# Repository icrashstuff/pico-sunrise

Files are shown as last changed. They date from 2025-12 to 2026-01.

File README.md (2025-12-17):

# pico-sunrise
A sunrise clock for RP2040 based microcontrollers

## Parts
- RP2040 based microcontroller (Raspberry Pi Pico) - Such as https://www.adafruit.com/product/4883
- PA1616S GPS Module - MTK3339 Chipset - Such as https://www.adafruit.com/product/746
- SK6812RGBW individually addressable LED strip - Such as https://www.adafruit.com/product/4913

## Configuration
[config.h](config.h)

## License (pico-sunrise)
Copyright (c) 2025 Ian Hangartner <icrashstuff at outlook dot com>

Permission is hereby granted, free of charge, to any person obtaining a
copy of this software and associated documentation files (the "Software"),
to deal in the Software without restriction, including without limitation
the rights to use, copy, modify, merge, publish, distribute, sublicense,
and/or sell copies of the Software, and to permit persons to whom the
Software is furnished to do so, subject to the following conditions:

The above copyright notice and this permission notice shall be included in
all copies or substantial portions of the Software.

THE SOFTWARE IS PROVIDED "AS IS", WITHOUT WARRANTY OF ANY KIND, EXPRESS OR
IMPLIED, INCLUDING BUT NOT LIMITED TO THE WARRANTIES OF MERCHANTABILITY,
FITNESS FOR A PARTICULAR PURPOSE AND NONINFRINGEMENT. IN NO EVENT SHALL THE
AUTHORS OR COPYRIGHT HOLDERS BE LIABLE FOR ANY CLAIM, DAMAGES OR OTHER
LIABILITY, WHETHER IN AN ACTION OF CONTRACT, TORT OR OTHERWISE, ARISING
FROM, OUT OF OR IN CONNECTION WITH THE SOFTWARE OR THE USE OR OTHER
DEALINGS IN THE SOFTWARE.

## License (pico-sdk and pico-examples)
Copyright 2020-2025 (c) 2020-2025 Raspberry Pi (Trading) Ltd.

Redistribution and use in source and binary forms, with or without modification, are permitted provided that the
following conditions are met:

1. Redistributions of source code must retain the above copyright notice, this list of conditions and the following
disclaimer.

2. Redistributions in binary form must reproduce the above copyright notice, this list of conditions and the following
disclaimer in the documentation and/or other materials provided with the distribution.

3. Neither the name of the copyright holder nor the names of its contributors may be used to endorse or promote products
derived from this software without specific prior written permission.

THIS SOFTWARE IS PROVIDED BY THE COPYRIGHT HOLDERS AND CONTRIBUTORS "AS IS" AND ANY EXPRESS OR IMPLIED WARRANTIES,
INCLUDING, BUT NOT LIMITED TO, THE IMPLIED WARRANTIES OF MERCHANTABILITY AND FITNESS FOR A PARTICULAR PURPOSE ARE
DISCLAIMED. IN NO EVENT SHALL THE COPYRIGHT HOLDER OR CONTRIBUTORS BE LIABLE FOR ANY DIRECT, INDIRECT, INCIDENTAL,
SPECIAL, EXEMPLARY, OR CONSEQUENTIAL DAMAGES (INCLUDING, BUT NOT LIMITED TO, PROCUREMENT OF SUBSTITUTE GOODS OR
SERVICES; LOSS OF USE, DATA, OR PROFITS; OR BUSINESS INTERRUPTION) HOWEVER CAUSED AND ON ANY THEORY OF LIABILITY,
WHETHER IN CONTRACT, STRICT LIABILITY, OR TORT (INCLUDING NEGLIGENCE OR OTHERWISE) ARISING IN ANY WAY OUT OF THE USE OF
THIS SOFTWARE, EVEN IF ADVISED OF THE POSSIBILITY OF SUCH DAMAGE.

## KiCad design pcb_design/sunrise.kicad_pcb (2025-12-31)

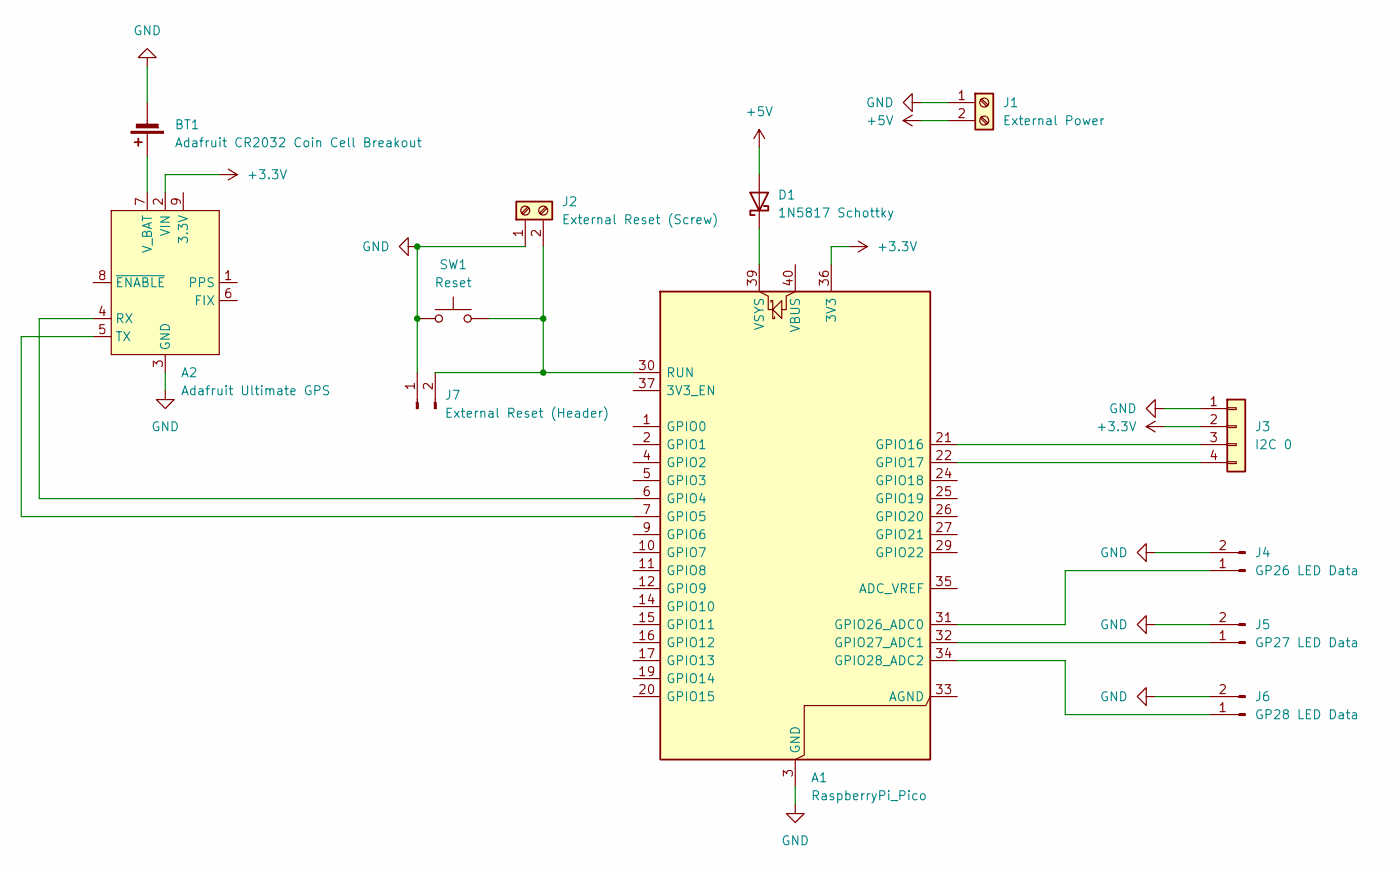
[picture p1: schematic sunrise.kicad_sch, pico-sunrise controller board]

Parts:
A1: RaspberryPi_Pico; RaspberryPi_Pico_Common_THT
A2: Adafruit Ultimate GPS; Adafruit_Ultimate_GPS_Breakout
BT1: Adafruit CR2032 Coin Cell Breakout; Adfruit_CR2032_Breakout
D1: 1N5817 Schottky; D_DO-41_SOD81_P10.16mm_Horizontal
J1: External Power; TerminalBlock_MetzConnect_Type101_RT01602HBWC_1x02_P5.08mm_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
J2: External Reset (Screw); TerminalBlock_MetzConnect_Type101_RT01602HBWC_1x02_P5.08mm_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
J3: I2C 0; PinHeader_1x04_P2.54mm_Vertical
J4: GP26 LED Data; PinHeader_1x02_P2.54mm_Vertical
J5: GP27 LED Data; PinHeader_1x02_P2.54mm_Vertical
J6: GP28 LED Data; PinHeader_1x02_P2.54mm_Vertical
J7: External Reset (Header); PinHeader_1x02_P2.54mm_Vertical
SW1: Reset; SW_TH_Tactile_Omron_B3F-100x

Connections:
+3.3V: A1.36 (3V3), A2.2 (VIN), J3.2
+5V: D1.2 (A), J1.2
GND: A1.3 (GND), A1.8 (GND), A1.13 (GND), A1.18 (GND), A1.23 (GND), A1.28 (GND), A1.38 (GND), A2.3 (GND), BT1.2 (-), J1.1, J2.1, J3.1, J4.2, J5.2, J6.2, J7.1, SW1.1
unnamed: A1.6 (GPIO4), A2.4 (RX)
unnamed: A1.7 (GPIO5), A2.5 (TX)
unnamed: A1.21 (GPIO16), J3.3
unnamed: A1.22 (GPIO17), J3.4
unnamed: A1.31 (GPIO26_ADC0), J4.1
unnamed: A1.32 (GPIO27_ADC1), J5.1
unnamed: A1.34 (GPIO28_ADC2), J6.1
unnamed: A1.30 (RUN), J2.2, J7.2, SW1.2
unnamed: A1.39 (VSYS), D1.1 (K)
unnamed: A2.7 (V_BAT), BT1.1 (+)

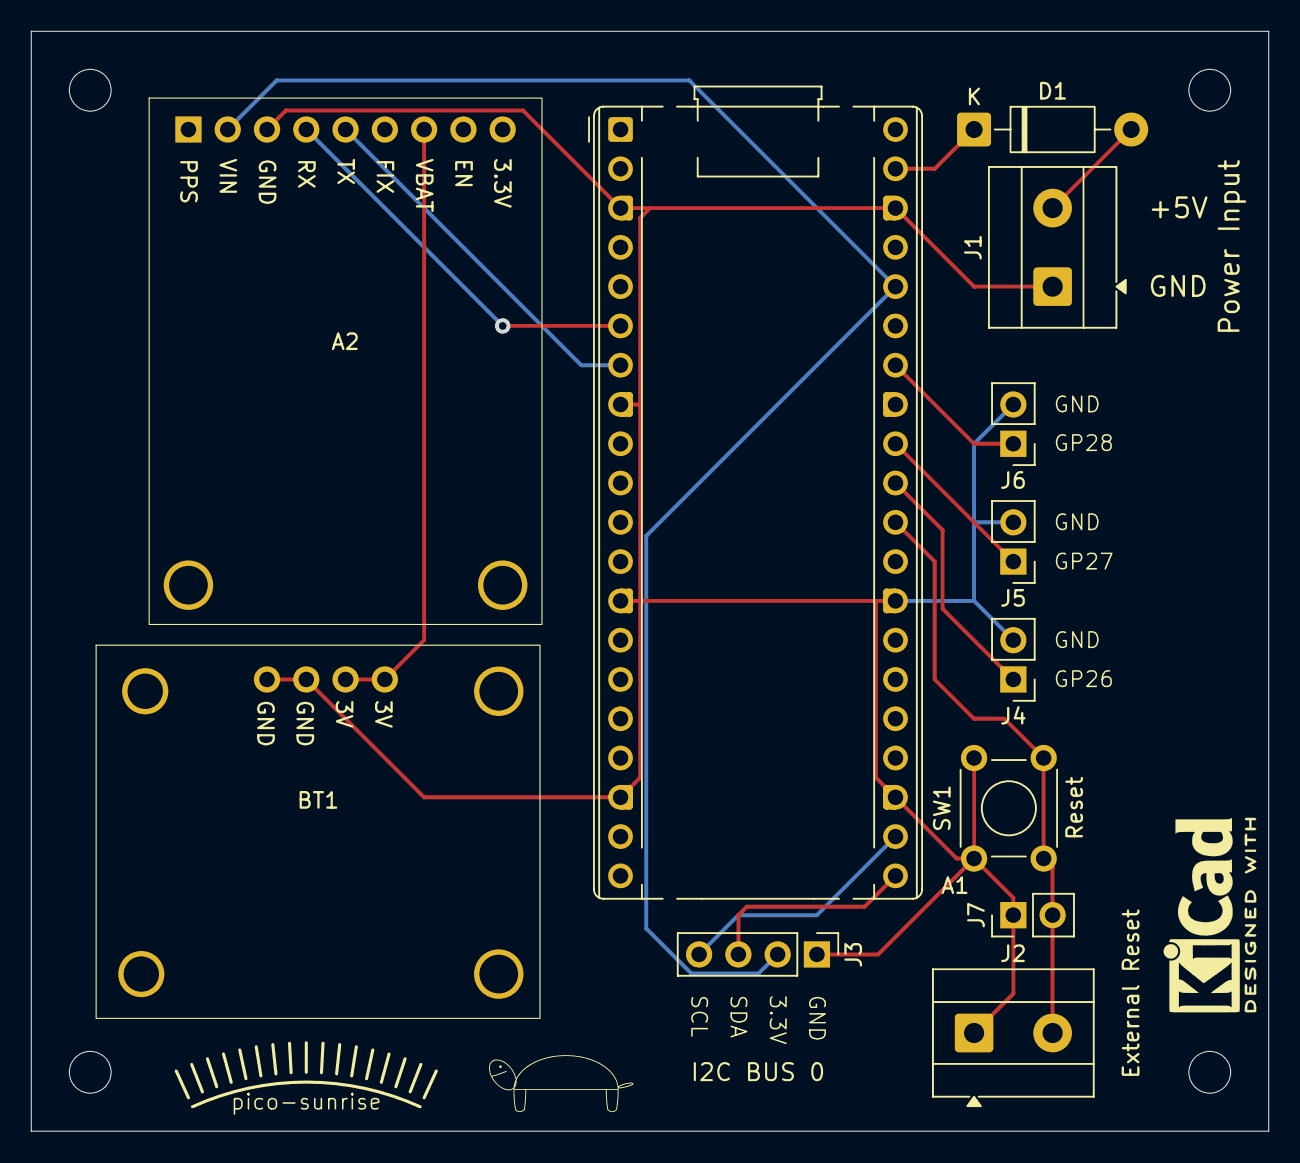
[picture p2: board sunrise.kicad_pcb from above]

Board: 2 copper layers, 80.0 x 71.1 mm, 13 parts (0 on the bottom side), 13 nets.

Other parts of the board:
SYM_KICAD: KiCad-Logo2_5mm_SilkScreen

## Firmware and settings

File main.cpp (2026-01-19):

/**
 * pico-sunrise - A sunrise clock for RP2040 based microcontrollers
 *
 * @file
 * @copyright
 * @parblock
 * SPDX-License-Identifier: MIT
 *
 * SPDX-FileCopyrightText: Copyright (c) 2025 Ian Hangartner <icrashstuff at outlook dot com>
 *
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
 * @brief Entry point of pico-sunrise
 */
/**
 * @mainpage
 * A sunrise clock for RP2040 based microcontrollers
 *
 * @par Parts required
 * - RP2040 based microcontroller (Raspberry Pi Pico) - Such as https://www.adafruit.com/product/4883\n
 * - PA1616S GPS Module - MTK3339 Chipset - Such as https://www.adafruit.com/product/746\n
 * - SK6812RGBW individually addressable LED strip - Such as https://www.adafruit.com/product/4913\n
 *
 * @par Configuration
 * @ref config.h
 */

#include "hardware/watchdog.h"
#include "pico/multicore.h"
#include "pico/stdlib.h"
#include <stdint.h>
#include <stdio.h>

#include "config.h"
#include "datetime.h"
#include "gps.h"
#include "led.h"
#include "license_text.h"
#include "sunrise.h"

#define arraysizeof(array) (sizeof(array) / sizeof(array[0]))

static void verify_time(const datetime_t& a, const datetime_t& b)
{
    if (a == b)
        return;

    printf("Time mismatch\n");
    a.print_to_stdout("a: ");
    b.print_to_stdout("b: ");
}

/**
 * Check that timezone correct is working
 */
static void check_dst()
{
    const timespan_t offset_dt = timespan_t(0, -8, 0, 0);
    const timespan_t offset_st = timespan_t(0, -9, 0, 0);
    verify_time(datetime_t((1762077599) * MICROSECONDS_PER_SECOND), datetime_t(2025, 11, 2, 9, 59, 59));
    verify_time(datetime_t((1762077600) * MICROSECONDS_PER_SECOND), datetime_t(2025, 11, 2, 10, 0, 0));
    verify_time(datetime_t((1762077599) * MICROSECONDS_PER_SECOND).get_tz_corrected(offset_st, offset_dt), datetime_t(2025, 11, 2, 1, 59, 59));
    verify_time(datetime_t((1762077600) * MICROSECONDS_PER_SECOND).get_tz_corrected(offset_st, offset_dt), datetime_t(2025, 11, 2, 1, 0, 0));

    verify_time(datetime_t((1741517999) * MICROSECONDS_PER_SECOND), datetime_t(2025, 3, 9, 10, 59, 59));
    verify_time(datetime_t((1741518000) * MICROSECONDS_PER_SECOND), datetime_t(2025, 3, 9, 11, 0, 0));
    verify_time(datetime_t((1741517999) * MICROSECONDS_PER_SECOND).get_tz_corrected(offset_st, offset_dt), datetime_t(2025, 3, 9, 1, 59, 59));
    verify_time(datetime_t((1741518000) * MICROSECONDS_PER_SECOND).get_tz_corrected(offset_st, offset_dt), datetime_t(2025, 3, 9, 3, 0, 0));
}

static int status_impl_dummy_func(const char*, va_list) { return 0; }

static int (*status_impl)(const char* fmt, va_list vlist) = vprintf;

#if defined(__GNUC__) || defined(__clang__)
#define formatting_attribute(fmtargnumber) __attribute__((format(__printf__, fmtargnumber, fmtargnumber + 1)))
#endif
static formatting_attribute(1) int status(const char* fmt, ...)
{
    va_list args;
    va_start(args, fmt);
    int r = status_impl(fmt, args);
    va_end(args);
    return r;
}

int main()
{
    watchdog_enable(WATCHDOG_INIT_TIME, 1);

    init_unix_time();

    stdio_init_all();

    const timespan_t offset_dt = TIMEZONE_OFFSET_DT;
    const timespan_t offset_st = TIMEZONE_OFFSET_ST;

    /* Reset to midnight 1970-1-11 (local time zone) */
    set_unix_time(MICROSECONDS_PER_DAY * 10 - offset_st.to_microseconds_since_1970());

    led_init(LED_IS_RGBW, LED_FREQUENCY, LED_GPIO);

#if SUNRISE_TESTING == 0
    multicore_launch_core1(gps_thread_func);
#endif

    uint64_t last_status_time = 0;
    loop_measure_t perf = {};

    watchdog_disable();
    watchdog_enable(WATCHDOG_LOOP_TIME, 1);

    uint32_t dither_count = 0;

    while (true)
    {
#if SUNRISE_TESTING == 0
        if (!time_reached(gps_data.watchdog_expiry_time))
            watchdog_update();
#else
        watchdog_update();
#endif
        const uint64_t loop_start_time = time_us_64();

        if (loop_start_time / STATUS_PRINT_INTERVAL != last_status_time / STATUS_PRINT_INTERVAL)
        {
            status_impl = vprintf;
            last_status_time = loop_start_time;
        }
        else
            status_impl = status_impl_dummy_func;

        check_dst();

        const datetime_t now = datetime_t::get_current_utc().get_tz_corrected(offset_st, offset_dt);
        const datetime_t midnight = datetime_t(now.year, now.month, now.day);

#if SUNRISE_TESTING
        // Negative offset from full_power_time
        const timespan_t rise_time = timespan_t(0, 0, 1, 0);

        // Positive offsets from midnight
        const datetime_t full_power_time = midnight + rise_time + timespan_t(0, 0, 0, 10);
        const datetime_t start_time = full_power_time - rise_time;
        const datetime_t off_allowed_time = full_power_time + timespan_t(0, 0, 0, 10);
        const datetime_t off_forced_time = off_allowed_time + timespan_t(0, 0, 0, 10);
#else
        // Negative offset from full_power_time
        const timespan_t rise_time = timespan_t(0, 0, 30, 0);

        // Positive offsets from midnight
        const datetime_t full_power_time = midnight + timespan_t(0, 6, 0, 0);
        const datetime_t start_time = full_power_time - rise_time;
        const datetime_t off_allowed_time = midnight + timespan_t(0, 7, 0, 0);
        const datetime_t off_forced_time = midnight + timespan_t(0, 7, 30, 0);
#endif

        char buf[64];

        status("\n\n\n======> Program info\n");
        status("Name: pico-sunrise\n");

        status("\n======> License text (pico-sunrise)\n");
        status("%s", license_text_pico_sunrise);

        status("\n======> License text (pico-sdk and pico-examples)\n");
        status("%s", license_text_pico_sdk_and_pico_examples);

        status("\n======> GPS Status\n");
        status("Firmware release:    %s\n", gps_data.firmware_release_str);
        status("Firmware build id:   %s\n", gps_data.firmware_build_id);
        status("Firmware internal 1: %s\n", gps_data.firmware_internal_1);
        status("Firmware internal 2: %s\n", gps_data.firmware_internal_2);
        status("Avg. loop time:   %lld us\n", gps_data.perf.average_loop_time);
        status("loops_per_second: %.3f\n", gps_data.perf.loops_per_second);
        status("Satellites used:  %d\n", gps_data.satellites_used);
        status("Fix status:       %d\n", gps_data.fix_status);
        status("NMEA Parsing: %s\n", gps_data.nmea_in_progress);
        status("NMEA Last:    %s\n", gps_data.nmea_last_full);

        float sunrise_factor = -1.0;

        if (start_time <= now && now < full_power_time)
        {
            double time_elapsed = now.to_microseconds_since_1970() - start_time.to_microseconds_since_1970();
            double time_to_full = full_power_time.to_microseconds_since_1970() - start_time.to_microseconds_since_1970();
            sunrise_factor = time_elapsed / time_to_full;
        }
        if (full_power_time <= now && now < off_forced_time)
            sunrise_factor = 1.0;

        int dither_steps_possible = perf.loops_per_second / float(DITHER_NOISE_TARGET_FREQUENCY);
        dither_steps_possible = dither_steps_possible < 1 ? 1 : dither_steps_possible;

        status("\n======> Sunrise status\n");
        status("Current time:     %s\n", now.print_to_buffer(buf, arraysizeof(buf)));
        status("Midnight:         %s\n", midnight.print_to_buffer(buf, arraysizeof(buf)));
        status("start_time:       %s\n", start_time.print_to_buffer(buf, arraysizeof(buf)));
        status("full_power_time:  %s\n", full_power_time.print_to_buffer(buf, arraysizeof(buf)));
        status("off_allowed_time: %s\n", off_allowed_time.print_to_buffer(buf, arraysizeof(buf)));
        status("off_forced_time:  %s\n", off_forced_time.print_to_buffer(buf, arraysizeof(buf)));
        status("sunrise_factor:   %f\n", sunrise_factor);
        status("Avg. loop time:   %lld us\n", perf.average_loop_time);
        status("loops_per_second: %.3f\n", perf.loops_per_second);
        status("Dither loops/sec: %.3f\n", perf.loops_per_second / float(dither_steps_possible));
        status("Dither cycles:    %d\n", dither_steps_possible);

        led_color_t* colors = (led_color_t*)calloc(LED_PIXEL_COUNT, sizeof(led_color_t));

        ++dither_count %= dither_steps_possible;
        sunrise_apply(float(dither_count) / float(dither_steps_possible), sunrise_factor, LED_WHITE_COLOR_TEMP, colors, LED_PIXEL_COUNT);

        led_swizzle_config_t led_config = {};
        led_config.byte_pos_r = LED_BYTE_POS_R;
        led_config.byte_pos_g = LED_BYTE_POS_G;
        led_config.byte_pos_b = LED_BYTE_POS_B;
        led_config.byte_pos_w = LED_BYTE_POS_W;

        led_push(colors, LED_PIXEL_COUNT, led_config);

        free(colors);

        perf.end_loop();
    }

    led_shutdown();

    return 0;
}

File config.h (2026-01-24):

/**
 * pico-sunrise - A sunrise clock for RP2040 based microcontrollers
 *
 * @file
 * @copyright
 * @parblock
 * SPDX-License-Identifier: MIT
 *
 * SPDX-FileCopyrightText: Copyright (c) 2025 Ian Hangartner <icrashstuff at outlook dot com>
 *
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
 * @brief Program configuration
 */
#pragma once

/******************************************************
 *                     LED CONFIG                     *
 ******************************************************/

/** Number of pixels */
#define LED_PIXEL_COUNT 144
/** Pixel hardware supports a white color component */
#define LED_IS_RGBW true
/** Tungsten color temperature (in kelvin) for the white color component */
#define LED_WHITE_COLOR_TEMP 3000
/** GPIO pin for datastream output */
#define LED_GPIO 26
/**
 * Datastream frequency (800kHz is almost guaranteed to work)
 *
 * In my experience higher frequencies can cause instability in high count led strips
 * I have successfully used SK6812RGBW-WS leds at 1000kHz in my setup, but your mileage may vary - Ian
 */
#define LED_FREQUENCY (1000 * 1000)

/** Position of red color component in datastream */
#define LED_BYTE_POS_R 2
/** Position of green color component in datastream */
#define LED_BYTE_POS_G 3
/** Position of blue color component in datastream */
#define LED_BYTE_POS_B 1
/** Position of white color component in datastream */
#define LED_BYTE_POS_W 0

/** Bit depth of red color component in datastream */
#define LED_BIT_DEPTH_R 8
/** Bit depth of green color component in datastream */
#define LED_BIT_DEPTH_G 8
/** Bit depth of blue color component in datastream */
#define LED_BIT_DEPTH_B 8
/** Bit depth of white color component in datastream */
#define LED_BIT_DEPTH_W 8

/******************************************************
 *                     GPS CONFIG                     *
 ******************************************************/

/**
 * UART port associated with @ref GPS_UART_TX_PIN and @ref GPS_UART_RX_PIN
 * @sa GPS_UART_TX_PIN
 * @sa GPS_UART_RX_PIN
 */
#define GPS_UART_ID uart1
/** GPS Serial Baudrate */
#define GPS_BAUD_RATE 9600
/** GPS Serial Data bits */
#define GPS_DATA_BITS 8
/** GPS Serial Stop bits */
#define GPS_STOP_BITS 1
/** GPS Serial Parity setting */
#define GPS_PARITY UART_PARITY_NONE
/** Echo all characters received by GPS UART */
#define GPS_ECHO false

/** GPIO pin for GPS UART transmit @sa GPS_UART_ID */
#define GPS_UART_TX_PIN 4
/** GPIO pin for GPS UART receive @sa GPS_UART_ID*/
#define GPS_UART_RX_PIN 5

/******************************************************
 *                  TIMEZONE CONFIG                   *
 ******************************************************/

/** Timezone offset during daylight savings time */
#define TIMEZONE_OFFSET_DT timespan_t(0, -8, 0, 0)
/** Timezone offset during standard time */
#define TIMEZONE_OFFSET_ST timespan_t(0, -9, 0, 0)

/******************************************************
 *                  WATCHDOG CONFIG                   *
 ******************************************************/

/** Watchdog delay in milliseconds for core 0 init until main loop */
#define WATCHDOG_INIT_TIME 5000

/** Watchdog delay in milliseconds for core 0 main loop */
#define WATCHDOG_LOOP_TIME 250

/** Maximum time in milliseconds that the GPS thread can hang before the watchdog is unhappy */
#define WATCHDOG_GPS_TIME 250

/******************************************************
 *                    MISC. CONFIG                    *
 ******************************************************/

/**
 * Changes time offsets so that sunrise blending can easily be tested
 *
 * @warning Disables GPS time sync
 */
#define SUNRISE_TESTING 0

/**
 * Target dither loops per second (in Hz) (24-60 are good values)
 *
 * Low values (< 24) could cause noticeable flickering
 * High values could cause transitions between brightness levels to be noticeable
 *
 * (Smooths transition between brightness levels)
 */
#define DITHER_NOISE_TARGET_FREQUENCY 48

/**
 * Minimum number of microseconds between each successive printing of program status
 */
#define STATUS_PRINT_INTERVAL (500 * 1000)

/**
 * Number of samples to use for average loop times
 */
#define LOOP_AVERAGE_SAMPLE_COUNT 256

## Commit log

2025-12-13 Add some functions related to using the default timer as a realtime clock
2025-12-14 Switch to C++ and add datetime handling structures
    - Added simple DST/Timezone correction
    - Datetime handling structures were inspired by Adafruit's RTClib, but the implementation is mine
    [main.cpp]
2025-12-14 Add bug note about GPS functions potentially dropping some packets
    [gps.cpp]
2025-12-14 Reduce frequency of gps_set_config() calls to 0.2Hz
2025-12-14 Fix lack of format string checking for status()
    [main.cpp]
2025-12-15 Add interface for WS2812 style leds
    - ws2812.pio from pico-examples does the heavy lifting
2025-12-16 Fix gps_write_nmea() not using full buffer
    [gps.cpp]
2025-12-17 Actually fix lack of format string checking for status()
    [main.cpp]
2025-12-17 Correct minor error in pico-sdk/pico-examples license
    [main.cpp]
2025-12-17 Fix (Or at least reduce) bug in gps_write_nmea() that causes some data from the GPS module to be lost
    [gps.cpp]
2025-12-20 Switch from only using sscanf(3) to extract data from NMEA packets to an argv like approach
2025-12-31 Add electrical schematic and PCB design
    [sunrise.kicad_pcb, sunrise.kicad_sch]
2026-01-18 Adjust LED_GPIO for PCB design
2026-01-19 Raise default LED_FREQUENCY (800kHZ -> 1100kHZ)
2026-01-19 Add dithering of led brightness
    - I not certain if what I have written is actually dithering, but it achieves
    my goal of masking quantization errors, so I'm not going to question it
    [config.h, main.cpp]
2026-01-24 Lower default LED_FREQUENCY (1100kHz ->1000kHz)
2026-01-25 Mix between top and bottom color temperatures instead of top and bottom color
2026-07-12 led_color_t change component types from int8_t to uint8_t
